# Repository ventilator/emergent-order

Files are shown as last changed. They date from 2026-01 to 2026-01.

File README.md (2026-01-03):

# /dev/emergent_order

An experiment in chaos and structure, presented at 39c3 (39th Chaos Communication Congress).

A 1×1×1m LED cube art installation filled with 1200 individually addressable WS2812B LEDs, creating a volumetric 3D display.

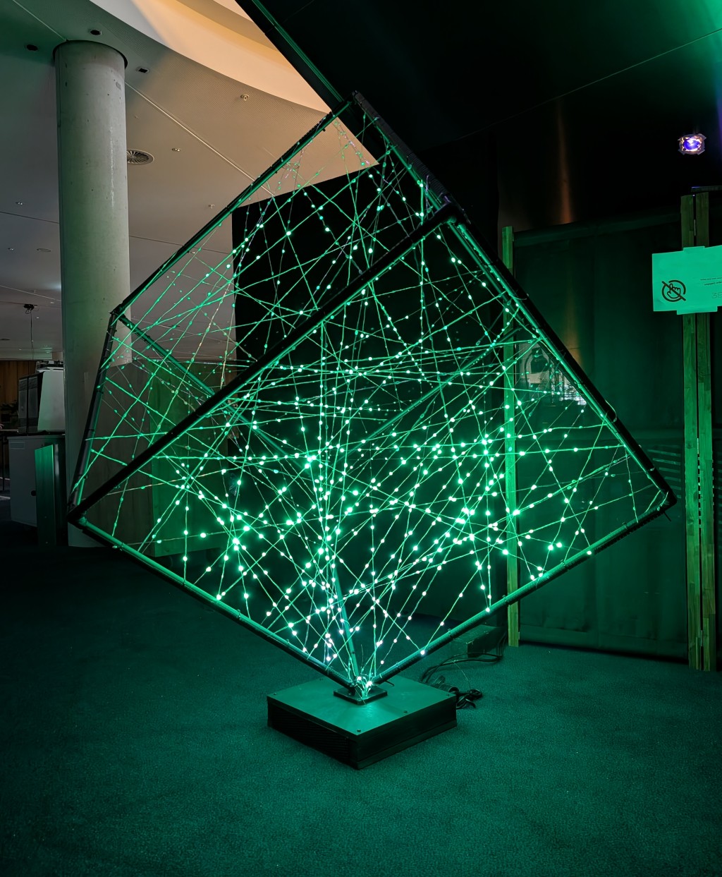
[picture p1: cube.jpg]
Assembled LED cube


## Overview

This repository contains most materials involved in creating the LED cube installation: software, firmware, animations, 3D mechanical parts, PCB designs, calibration tools, and documentation. The aim is to document the complete structure of the cube and make relevant tools and designs available to others who want to build their own version, learn from the project, create derivative works, or apply these concepts in entirely new ways.

## Project Structure

This repository contains the following subdirectories:

**Note:** Some directories mentioned below may not yet be available in the repository. We are actively uploading the remaining materials and expect to have everything published within the next few days.

### Hardware & Electronics

- **`controller_pcb/`** - KiCad project for a high-performance 8-channel WS2812 controller based on the Raspberry Pi Pico. Features include USB streaming mode, standalone operation with built-in test patterns, SD card playback, comprehensive monitoring (voltage, current, temperature), and per-channel smart fuse protection (3.7A). Supports up to 200 LEDs per channel at 60Hz. See [controller_pcb/README.md](controller_pcb/README.md) for complete specifications.

- **`pico_firmware/`** - C firmware for the Raspberry Pi Pico that drives 8 independent WS2812B channels via PIO hardware. Features gamma correction, automatic current limiting, hardware monitoring (temperature, current, voltage), channel fault detection, and built-in test patterns including a ternary-encoded calibration pattern for camera-based position recovery. See [pico_firmware/README.md](pico_firmware/README.md) for protocol specification and development setup.

- **`mechanical/`** - 3D printable parts (base, corners, combs, controller mounts) and carbon fiber tube specifications for building the physical cube structure. See [mechanical/README.md](mechanical/README.md) for details.

### Software & Control

- **`showrunner/`** - Node.js service that plays LED animations on the cube, streaming frames at 30-60 FPS over serial to the Pico firmware. Supports hot-swappable animations and WebSocket interface for live streaming. See [showrunner/README.md](showrunner/README.md) for details.

- **`animations/`** - JavaScript animation scripts that generate LED patterns using 3D math (SDF primitives, planes, spheres, fire effects, etc.). See [animations/README.md](animations/README.md) for examples and animation format.

- **`animation_designer/`** - Web-based tool for designing and previewing animations before deploying them to the cube. See [animation_designer/README.md](animation_designer/README.md) for usage instructions.

### Calibration & Utilities

- **`calibration/`** - Tools for recovering 3D LED positions from video captures of the cube. Includes video frame extraction, LED detection with ternary color-coded identification, and multi-camera 3D triangulation with bundle adjustment. Features both Python CLI tools and a web-based detector with real-time visualization. See [calibration/README.md](calibration/README.md) for complete workflow and encoding scheme documentation.

- **`ws2serial/`** - Python utility for testing and interfacing with WS2812 LED strips over USB serial during development. Provides a WebSocket-to-serial adapter allowing the animation designer web tool to stream pixel data over the network to the Pico controller. See [ws2serial/README.md](ws2serial/README.md) for details.

- **`testdevice/`** - MicroPython code for ESP32-C3 to quickly test single LED strings during installation and teardown. See [testdevice/README.md](testdevice/README.md) for details.

### Prototypes

- **`minikube/`** - Smaller ~20×20×20cm prototype cube with MicroPython firmware and mechanical designs for ESP32-C3. See [minikube/README.md](minikube/README.md) for details.

## Technical Specifications

- **Physical size:** 1×1×1 meter cube
- **LEDs:** 1200 individually addressable WS2812B LEDs
- **Structure:** Carbon fiber tubes (20×18mm) with 3D printed corner connectors
- **Controller:** Raspberry Pi Pico-based 8-channel controller (can be driven by Raspberry Pi 3 or run standalone)
- **Power:** Custom 4-layer PCB with 8-channel power distribution, smart fuse protection (3.7A per channel), and comprehensive monitoring
- **Software:** Node.js showrunner + JavaScript animation framework (USB streaming), or standalone test patterns
- **Communication:** USB serial (Pi 3 → Pico), PIO-based WS2812B output, WebSocket interface for live animation streaming

## Development Approach

Most of the code in this project was synthesized ("vibe coded") using various Anthropic Claude models. The goal was to rapidly prototype and get something working, so the code may not be well understood in all places or may contain bugs. However, key decisions about architecture, algorithms and artistic content were provided by humans, just not manually implemented line-by-line.

## License

See the license files in individual directories or license text in source files.

In general:
- **Code/Software:** MIT License
- **3D Models:** CC-BY 4.0
- **PCB Designs:** CERN-OHL-W (CERN Open Hardware License - Weakly Reciprocal)

## Contributing

This project was created for 39c3. Feel free to fork, modify, and create your own versions. If you build something based on this work, we'd love to hear about it!

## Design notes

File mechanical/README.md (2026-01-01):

# Mechanical Parts for LED Cube

This directory contains all the 3D models and specifications for building the physical structure of the 1×1×1m LED cube.

## Overview

The cube structure consists of:
- **Carbon fiber tubes** forming the main frame (12 edges of the cube)
- **3D printed connectors** to join the tubes at corners and base
- **3D printed cable management** combs to route LED wires
- **MDF base** housing all electronics
- **Controller mounting hardware**

## Bill of Materials

### Structural Components

#### Carbon Fiber Tubes

Ordered from "CARBON TIME" store on AliExpress:
- **Store:** [CARBON TIME](https://de.aliexpress.com/store/911756291)
- **Product:** [20mm Carbon Fiber Tubes](https://de.aliexpress.com/item/1005002337416341.html)

**Quantities needed:**
- 9× tubes 20×18×1000mm (outer × inner × length)
- 3× tubes 20×16×1000mm (for bottom connections to base)
  - Note: 20×18mm can be used for everything if you prefer consistency

**Finish:** Twill matte

#### MDF Base

The base houses all electronics and provides structural support:

- **Construction:** Two pieces of 40×40cm MDF + battens screwed together
- **Finish:** Painted black
- **Features:**
  - Houses Raspberry Pi 4, controller PCB, power supply
  - Covered by PLA honeycomb grills for visual cover and ventilation
  - 2× Noctua 40×40mm fans in the back for airflow
  - Cable access holes

### 3D Printed Parts

All 3D model files (.3mf format) are included in this directory. CAD source files are available on Onshape (links below).

#### Base Corner Connector

**File:** `base.3mf`

**Onshape CAD:** [View on Onshape](https://cad.onshape.com/documents/e40c83297a2b759d68be7f6e/w/c118c41bf27f27ad78296554/e/638a71450e9c66e4a3123774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)

**Quantity:** 1

**Purpose:** Holds three carbon fiber pipes at the bottom of the cube and secures them to the MDF base plate.

**Features:**
- Secured to base with 4× M5 screws
- Cable routing hole for LED wires

**Print Settings:**
- Material: PETG (recommended for strength)
- Layer height: 0.2mm
- Perimeter walls: 4+ for strength

**Assembly Notes:**
- This is a high-stress part - the 1m CF tubes create significant leverage
- While PETG prints work, aluminum parts would be more durable for permanent installations
- Handle the cube carefully to avoid breaking this part
- Print spare/replacement parts

---

#### Corner Connector

**File:** `corner.3mf`

**Onshape CAD:** [View on Onshape](https://cad.onshape.com/documents/e40c83297a2b759d68be7f6e/w/c118c41bf27f27ad78296554/e/c4481eaa0fdde92928e6f618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)

**Quantity:** 7 (one for each corner of the cube, except base)

**Purpose:** Connects 3 carbon fiber pipes at 90° angles to form cube corners.

**Print Settings:**
- Material: PETG
- Layer height: 0.2mm
- Shells/perimeters: 4+
- Orientation: Place on corner point for symmetric print

**Assembly Notes:**
- Friction fit design: pipes press into the connector
- Tolerances may vary: be prepared to file, sand, or heat-form for proper fit
- If fit is too loose: wrap electrical tape around CF tube end before inserting
- For permanent installations: consider adding set screws to secure tubes
- Not verified for prolonged thermal cycling (sun, seasons, etc.)

---

#### Cable Management Comb

**File:** `comb.3mf`

**Onshape CAD:** [View on Onshape](https://cad.onshape.com/documents/e40c83297a2b759d68be7f6e/w/c118c41bf27f27ad78296554/e/f5acbb86f4773182431e6e56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)

**Quantity:** 60 total (5 per 1m CF pipe × 12 pipes)

**Purpose:** Guides and organizes LED string wires along the carbon fiber tubes.

**Attachment:** Zip ties

**Print Settings:**
- Material: PLA (no significant structural load)
- Layer height: 0.2mm

**Assembly Notes:**
- Attach with small zip ties to CF tubes
- Route LED wires through the comb teeth

---

#### Controller PCB Mount

**File:** `controller_mount.3mf` and `controller_clamp.3mf`

**Onshape CAD:** [View on Onshape](https://cad.onshape.com/documents/70f768b329ba066f39a94f12/w/328bc72038fa8f24f8fcde96/e/15a5e0a3f1c87c68c4469b0a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)

**Quantity:** 1

**Purpose:** Provides solid base for the controller PCB and strain relief for LED cables.

**Features:**
- Screw mounting points for PCB (M3 threaded inserts required)
- Cable clamps for LED string wire management

**Print Settings:**
- Material: PLA or PETG
- Draft settings acceptable (fast print)
- May not need top/bottom solid layers (just perimeters)

**Assembly Notes:**
- Install M3 threaded inserts (heat-set recommended)
- Secure PCB with M3 screws
- Route LED cables through clamps before connecting to PCB

## License

3D models are licensed under [CC-BY 4.0](https://creativecommons.org/licenses/by/4.0/)

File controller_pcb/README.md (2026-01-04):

# 8-Channel WS2812 Controller

High-performance WS2812 LED controller based on the Raspberry Pi Pico, designed for driving large LED installations with up to 8 independent channels.

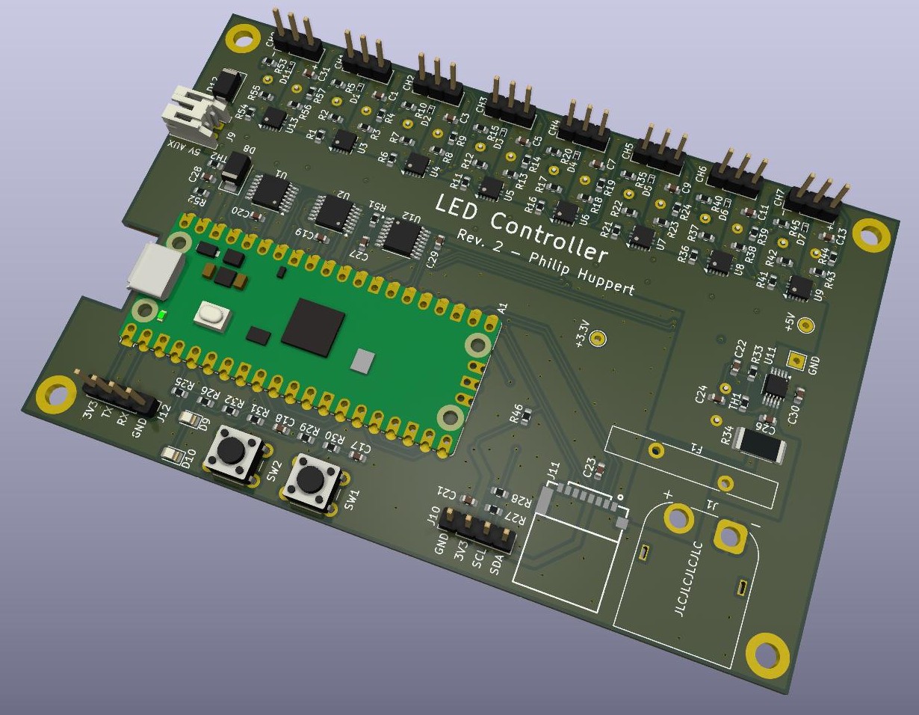
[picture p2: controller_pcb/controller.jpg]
Controller PCB


## Features

- **8 independent WS2812 channels** - Drive up to 200 LEDs per channel @ 60Hz
- **Multiple operation modes:**
  - USB streaming mode (real-time control from computer)
  - Standalone mode (run animations directly on Pico)
  - SD card playback mode (hardware ready, firmware not yet implemented)
- **Built-in test patterns** for calibration and diagnostics
- **Comprehensive monitoring** - voltage, current, and temperature sensing
- **Advanced protection** - smart fuses, PTC, and TVS diodes

## Hardware Specifications

### PCB Design
- **4-layer PCB**
- **Raspberry Pi Pico** microcontroller (direct solder or via header)
- Compact form factor

### LED Output Channels
- **8 independent channels** driven via PIO state machines
- **3.3V to 5V level shifters** for reliable WS2812 communication
- **Smart fuse protection** (TPS259251) set to 3.7A per channel
- **TVS diodes** on all data lines for protection

### Power System
- **5V input** via XT60 connector
- **Input PTC** for overcurrent protection
- **5V auxiliary output** for powering additional devices (fans, Raspberry Pi, etc.)
- **INA226 current/voltage monitor** for real-time power consumption tracking

### Sensing and Monitoring
- **Input power monitoring** via INA226 (voltage and current)
- **2× NTC temperature sensors** for thermal monitoring
- **Per-channel voltage sensing** via 8:1 analog multiplexer
- **Trip detection** - automatic fault detection when channels go offline

### User Interface
- **2 buttons** for pattern selection and reset
- **2 status LEDs** (activity and fault indicators)
- **I2C OLED display header** for local status display (optional)

### Storage
- **SD card slot** for storing animations and configuration files
- **Note:** SD card support is not currently implemented in the firmware, but it was verified that the slot is correctly wired and the Pico can access data on an SD card

## Implementation & Assembly Notes

### Capacitors
- The layout contains space for through-hole capacitors on the input rail and on each output rail
- These were not fitted on the controller that ran the installation and can be considered optional

### Channel Output Connectors
- The pin headers on the channel outputs do fit into JST-SM plugs commonly used with LED strings
- However, the spacing of the pin headers is too tight for two JST-SM plugs next to each other
- There is no mechanical interlocking, and if you pass any decent current (over 1A) these connections will get quite warm, especially if not well inserted
- **Recommendation:** For the controller used in the installation, we soldered pigtails with JST-SM sockets directly to the controller PCB for more reliable connections

### Pico Mounting
- The Pi Pico was mounted with a socket to allow easier exchange in case of failure
- This is recommended over direct soldering for serviceability

## Firmware

See `../pico_firmware/` for the Raspberry Pi Pico firmware source code.

## License

Hardware design licensed under **CERN-OHL-W** (CERN Open Hardware License - Weakly Reciprocal)

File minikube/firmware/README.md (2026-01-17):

# Minikube Firmware

MicroPython firmware to drive the LEDs of the minikube (single WS2812 string) with an ESP32-C3. Different ESP models or other microcontrollers may also work, provided they are capable of running MicroPython and driving a WS2812 string.

## Wiring Electronics

1. **Connect LED strip:**
   - Either solder strip directly to ESP32 pads, or use a connector
   - LED strip 5V to ESP32 VBUS
   - LED strip GND to ESP32 GND
   - LED data input to ESP32 pin 20 (configurable in `config.py`)

2. **Optional level shifter:**
   - Insert 3.3V to 5V level shifter between ESP32 and LED data line
   - A small PCB with 4× WS2812 LEDs works well for this purpose ([AliExpress link](https://de.aliexpress.com/item/1005010216258357.html))
   - Not strictly necessary but improves signal integrity

4. **Power the ESP32:**
   - Connect ESP32 via USB

   - Especially during development, while the ESP is connected to the USB port, it can happen that the PC does not deliver the required 500mA+ of power. On the console one can observe messages like "brown out detected, rebooting". If this is the case, consider powering the LED strip externally by connecting the 5V line of the LED strip to an external power supply. Do not forget to connect GND

## Installation Instructions

### 1. Flash MicroPython

Download MicroPython firmware for ESP32-C3 from [micropython.org](https://micropython.org/download/ESP32_GENERIC_C3/) and flash it using esptool.

### 2. Configure Settings

Edit `config.py` to configure:
- GPIO pin numbers
- Number of LEDs
- Other hardware-specific settings (see comments in file)

### 3. Upload Firmware

Upload all files from this directory to the ESP32 using [mpremote](https://docs.micropython.org/en/latest/reference/mpremote.html):

```bash
mpremote connect /dev/ttyACM0 cp -r * :
```

Windows (with com3 as the com port of your device):
```cmd
py -m mpremote connect com3 cp -r *
```

### 4. Verify Operation

Monitor serial output to ensure everything runs correctly:

```bash
mpremote connect /dev/ttyACM0
```

### 5. Calibrate LED Positions

For the animations to look correct, the exact 3D position of each LED must be known:

1. Press the boot button on the ESP32 to cycle to the **Calibration** animation
   - The calibration pattern displays a ternary-encoded LED ID sequence with magenta sync markers
   - Compatible with the camera-based calibration tools in `../../calibration/`
2. Capture calibration videos of the cube from multiple perspectives (6+ angles recommended)
   - Use fixed camera settings (exposure, white balance, focus)
   - Record the full calibration sequence from each angle
3. Process the videos and generate LED position data using the tools in `../../calibration/`
4. Upload the LED calibration results (positions) as `solution1.txt` to the ESP32:
   ```bash
   mpremote connect /dev/ttyACM0 cp solution1.txt :
   ```

After calibration, the volumetric animations will render correctly!

## Usage

- **Cycle animations:** Press the boot button of the ESP32
- **Modify animations:** Edit Python files in `animations/`
- **Create new animations:** Subclass `AnimationBase` and implement the `render()` method
- **Adjust speed/colors:** Modify parameters in the animation files

## Animation Framework

The firmware includes a simple animation framework:

- **`animation_base.py`** Base class for animations
- **`sdf_primitives.py`** Signed distance field primitives for 3D shapes
- **`math_utils.py`** Vector math, noise functions
- **`color_utils.py`** Color manipulation and conversion
- **`coordinate_loader.py`** Loads LED positions from calibration file

Example animations included:
- **`plane_animation.py`** Animated plane sweeping through the cube
- **`sphere_animation.py`** Pulsing sphere effect
- **`calibration.py`** Ternary-encoded calibration pattern for camera-based position recovery

## License

Firmware is licensed under MIT

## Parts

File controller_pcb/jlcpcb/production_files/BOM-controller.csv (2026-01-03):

Comment | Designator | Footprint | LCSC | Quantity
1000uF | C25 | C_Radial_D12.5mm_H20.0mm_P5.00mm | C88743 | 1
2.5m | R34 | R_2512_6332Metric | C7420002 | 1
470uF | C10,C12,C14,C2,C32,C4,C6,C8 | C_Radial_D10.0mm_H16.0mm_P5.00mm | C88732 | 8
74AHCT125 | U1,U2 | TSSOP-14_4.4x5mm_P0.65mm | C36365 | 2
74HC4051 | U12 | TSSOP-16_4.4x5mm_P0.65mm | C352826 | 1
Conn_01x02 | J1 | AMASS_XT60PW-M_1x02_P7.20mm_Horizontal | C98732 | 1
ESD9L5.0ST5G | D1,D11,D2,D3,D4,D5,D6,D7 | D_SOD-923 | C82326 | 8
INA226 | U11 | VSSOP-10_3x3mm_P0.5mm | C49851 | 1
Micro_SD_Card | J11 | TF-SMD_TF-021B-H265 | C498185 | 1
SS34 | D12,D8 | D_SMA | C8678 | 2
TPS259251 | U13,U3,U4,U5,U6,U7,U8,U9 | VSON-10-1EP_3x3mm_P0.5mm_EP1.65x2.4mm_ThermalVias | C527680 | 8
TRA1600 | F1 | Fuse_Bourns_MF-RHT1300 | C5678529 | 1
10K | R32 | R_0603_1608Metric |  | 1
10K | R29 | R_0603_1608Metric |  | 1
1K | R6 | R_0603_1608Metric |  | 1
47K | R44 | R_0603_1608Metric |  | 1
0.1uF | C19 | C_0603_1608Metric |  | 1
47K | R39 | R_0603_1608Metric |  | 1
0.1uF | C31 | C_0603_1608Metric |  | 1
47K | R19 | R_0603_1608Metric |  | 1
100K | R37 | R_0603_1608Metric |  | 1
0.1uF | C7 | C_0603_1608Metric |  | 1
330 | R10 | R_0603_1608Metric |  | 1
1K | R26 | R_0603_1608Metric |  | 1
33K | R3 | R_0603_1608Metric |  | 1
1K | R54 | R_0603_1608Metric |  | 1
1K | R11 | R_0603_1608Metric |  | 1
1K | R30 | R_0603_1608Metric |  | 1
0.1uF | C27 | C_0603_1608Metric |  | 1
0.1uF | C13 | C_0603_1608Metric |  | 1
330 | R35 | R_0603_1608Metric |  | 1
100K | R12 | R_0603_1608Metric |  | 1
33K | R38 | R_0603_1608Metric |  | 1
33K | R18 | R_0603_1608Metric |  | 1
0.1uF | C26 | C_0603_1608Metric |  | 1
10K | R28 | R_0603_1608Metric |  | 1
1K | R25 | R_0603_1608Metric |  | 1
0.1uF | C5 | C_0603_1608Metric |  | 1
1K | R41 | R_0603_1608Metric |  | 1
330 | R40 | R_0603_1608Metric |  | 1
100K | R42 | R_0603_1608Metric |  | 1
0.1uF | C9 | C_0603_1608Metric |  | 1
1K | R21 | R_0603_1608Metric |  | 1
33K | R43 | R_0603_1608Metric |  | 1
33K | R23 | R_0603_1608Metric |  | 1
330 | R53 | R_0603_1608Metric |  | 1
100K | R17 | R_0603_1608Metric |  | 1
0.1uF | C24 | C_0603_1608Metric |  | 1
10K | R52 | R_0603_1608Metric |  | 1
47K | R9 | R_0603_1608Metric |  | 1
0.1uF | C22 | C_0603_1608Metric |  | 1
0.1uF | C28 | C_0603_1608Metric |  | 1
1K | R16 | R_0603_1608Metric |  | 1
100K | R2 | R_0603_1608Metric |  | 1
TestPoint | TP1 | TestPoint_THTPad_2.0x2.0mm_Drill1.0mm |  | 1
TestPoint | TP3 | TestPoint_THTPad_D2.0mm_Drill1.0mm |  | 1
10K | TH1 | R_0603_1608Metric |  | 1
330 | R5 | R_0603_1608Metric |  | 1
100K | R7 | R_0603_1608Metric |  | 1
100K | R55 | R_0603_1608Metric |  | 1
10K | R51 | R_0603_1608Metric |  | 1
33K | R56 | R_0603_1608Metric |  | 1
330 | R45 | R_0603_1608Metric |  | 1
10K | R33 | R_0603_1608Metric |  | 1
47K | R24 | R_0603_1608Metric |  | 1
0.1uF | C29 | C_0603_1608Metric |  | 1
10K | R27 | R_0603_1608Metric |  | 1
10K | TH2 | R_0603_1608Metric |  | 1
1K | R36 | R_0603_1608Metric |  | 1
0.1uF | C21 | C_0603_1608Metric |  | 1
1K | R31 | R_0603_1608Metric |  | 1
0.1uF | C1 | C_0603_1608Metric |  | 1
1K | R1 | R_0603_1608Metric |  | 1
0.1uF | C3 | C_0603_1608Metric |  | 1
0.1uF | C30 | C_0603_1608Metric |  | 1
47K | R14 | R_0603_1608Metric |  | 1
0.1uF | C23 | C_0603_1608Metric |  | 1
0.1uF | C11 | C_0603_1608Metric |  | 1
0.1uF | C18 | C_0603_1608Metric |  | 1
330 | R20 | R_0603_1608Metric |  | 1
0.1uF | C17 | C_0603_1608Metric |  | 1
47K | R57 | R_0603_1608Metric |  | 1
TestPoint | TP2 | TestPoint_THTPad_D2.0mm_Drill1.0mm |  | 1
33K | R8 | R_0603_1608Metric |  | 1
33K | R13 | R_0603_1608Metric |  | 1
100K | R22 | R_0603_1608Metric |  | 1
0.1uF | C20 | C_0603_1608Metric |  | 1
330 | R15 | R_0603_1608Metric |  | 1
47K | R4 | R_0603_1608Metric |  | 1
Conn_01x02 | J9 | JST_PH_S2B-PH-K_1x02_P2.00mm_Horizontal |  | 1
10K | R46 | R_0603_1608Metric |  | 1

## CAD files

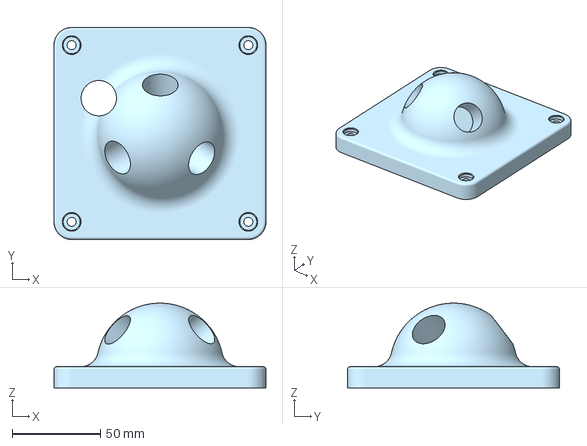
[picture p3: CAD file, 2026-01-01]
mechanical/base.3mf
120.0 x 120.0 x 48.0 mm

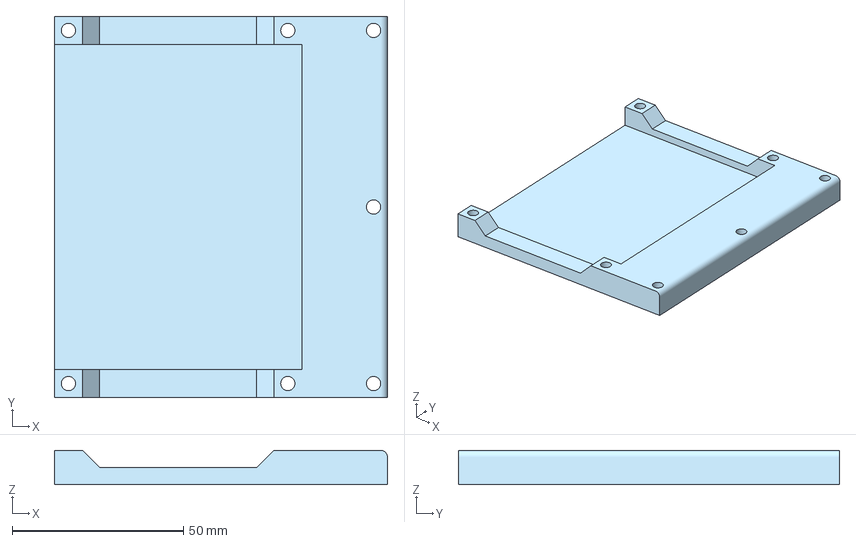
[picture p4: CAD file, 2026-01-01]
mechanical/controller_mount.3mf
97.2 x 111.2 x 10.0 mm

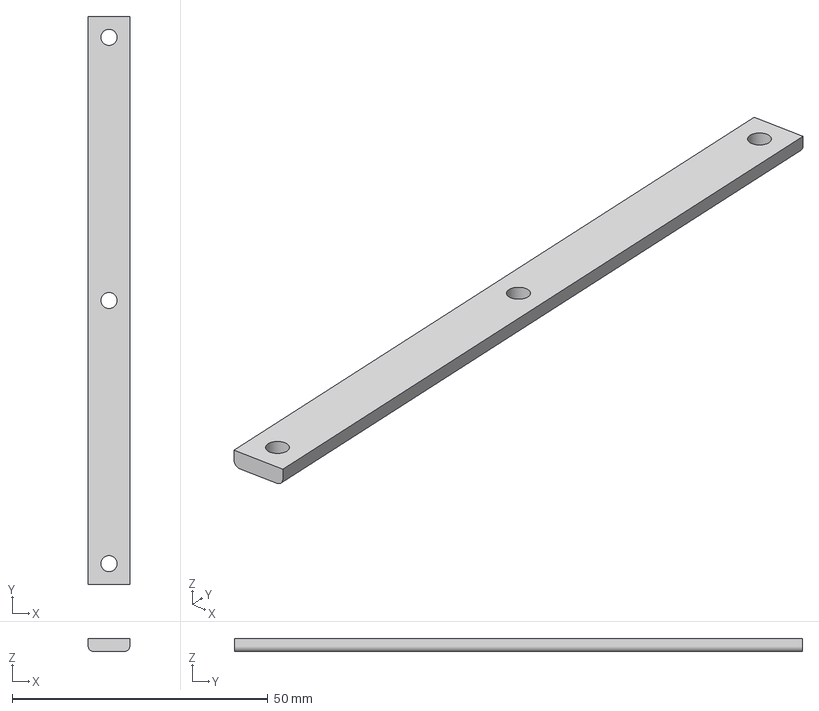
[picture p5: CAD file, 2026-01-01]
mechanical/controller_clamp.3mf
8.15 x 111.2 x 2.50 mm

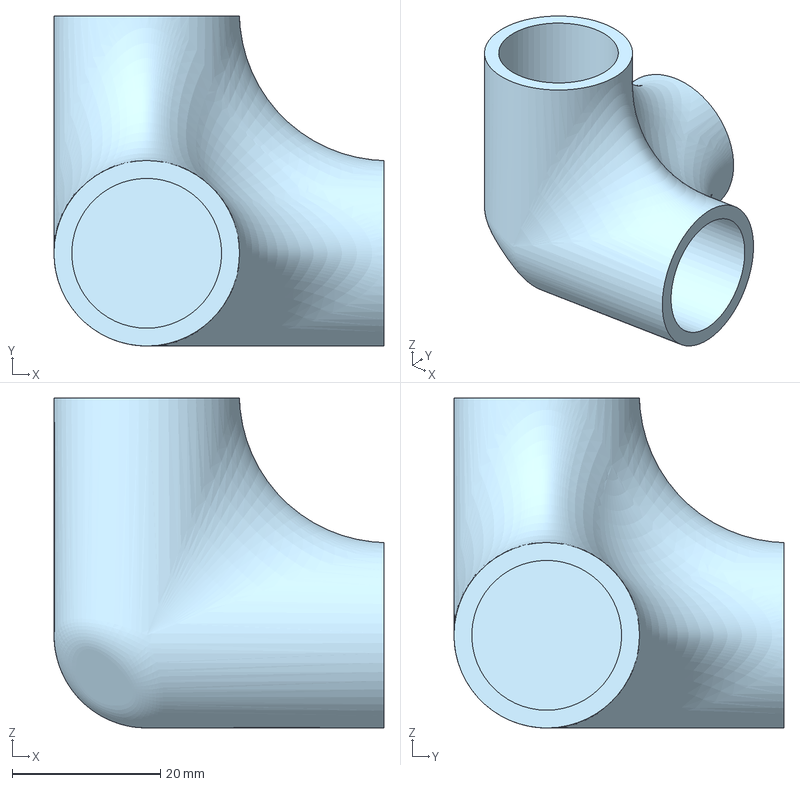
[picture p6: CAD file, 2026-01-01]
mechanical/corner.3mf
44.5 x 44.5 x 44.5 mm

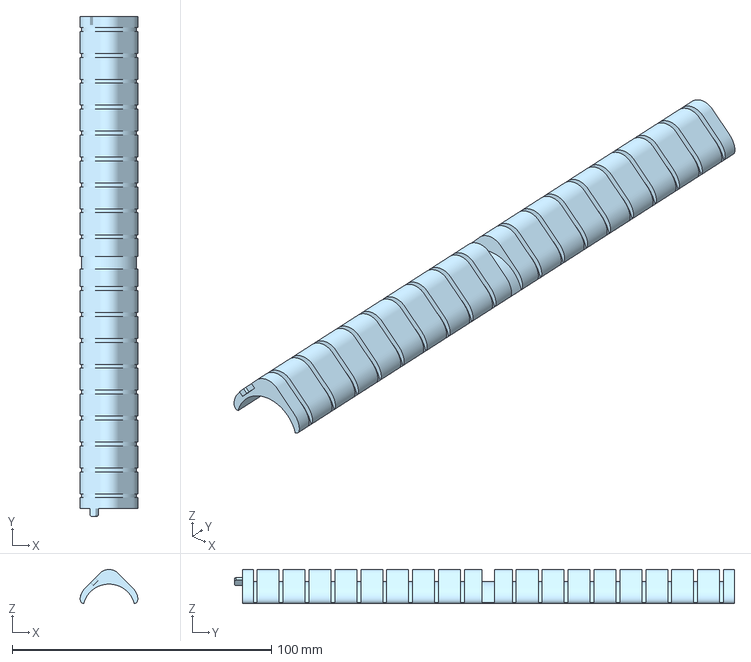
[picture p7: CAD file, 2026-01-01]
mechanical/comb.3mf
22.3 x 193.0 x 13.1 mm

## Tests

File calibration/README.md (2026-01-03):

# Cube Calibration Utils

Tools for recovering 3D LED positions from the chaotic LED cube installation.

## Overview

This calibration system uses a ternary color-coded identification scheme where LEDs flash specific color sequences that encode their unique IDs. Multiple camera perspectives capture these sequences, and the 2D detections are triangulated to recover 3D positions.

## Tools

### frame_extractor.py
Automated video processing tool that extracts calibration frames from video recordings.

**What it does:**
- Analyzes video frame-by-frame to detect brightness changes
- Identifies calibration sequences by detecting magenta color markers
- Extracts frames between magenta markers (configurable sequence length, default: 9 frames)
- Extracts corresponding dark frames for background subtraction
- Saves extracted frames as PNG files with structured naming

**Usage:**
```bash
uv run frame_extractor.py video.mp4
```

**Output:** PNG files named `{video_name}_subseq_{N}_{frame_number}.png` and `{video_name}_subseq_{N}_{frame_number}_dark.png`

### led_detector.html (+ .js + .css)
Modern web-based LED detector with real-time visual feedback.

**What it does:**
- Loads image sequences from a single camera perspective
- Performs background subtraction using dark frames
- Classifies pixel colors as Red, Green, Blue, or White
- Decodes ternary LED IDs from color sequences
- Validates LED IDs using checksum
- Computes LED centroid positions
- Exports results as text files

**Usage:**
Open `led_detector.html` in a web browser, drag and drop images (including dark frame and optional mask frame).

**Output format:**
```
FRAME_SIZE width height
LED_subseq_id x y
LED_subseq_id x y
...
```

### led_detector_sequenced.py
Command-line Python LED detector (legacy, less convenient than HTML version).

**What it does:**
Same functionality as HTML version but controlled via command-line arguments and environment variables.

**Usage:**
```bash
LOG_LEVEL=INFO DEBUG_OUTPUT=1 uv run led_detector_sequenced.py images/*.png
```

**Environment variables:**
- `LOG_LEVEL`: Logging verbosity (DEBUG, INFO, WARNING, ERROR)
- `DEBUG_OUTPUT`: Set to "1" to generate debug images

**Output:** Writes results to stdout, debug images if enabled

### rename_video.py
Simple utility for batch renaming video files (no external dependencies).

**What it does:**
Renames Google Pixel video files (format: `PXL_*.mp4`) to simple sequential names (`a.mp4`, `b.mp4`, `c.mp4`, etc.).

**Usage:**
```bash
./rename_video.py [directory]
```

If no directory is specified, operates on current directory.

### led_solver.py
3D reconstruction tool that triangulates LED positions from multiple camera perspectives.

**What it does:**
- Loads 2D LED observations from multiple cameras
- Performs camera calibration (estimates camera poses)
- Triangulates 3D LED positions using multiple views
- Applies bundle adjustment optimization
- Implements robust outlier rejection:
  - Statistical outlier detection (MAD-based)
  - RANSAC for camera pose estimation
  - Reprojection error validation
  - Iterative refinement
- Generates 3D visualization

**Usage:**
```bash
uv run led_solver.py camera1.txt camera2.txt camera3.txt --output solution.txt --viz visualization.html
```

**Optional arguments:**
- `--output`, `-o`: Output file for 3D LED positions
- `--viz`, `-v`: Generate HTML visualization
- `--top`: Comma-separated LED IDs near top (for orientation)
- `--bottom`: LED IDs near bottom
- `--left`: LED IDs near left
- `--right`: LED IDs near right

**Output format:**
```
LED_0000 -0.032561 0.357653 -0.102755
LED_0001 0.123456 -0.234567 0.345678
LED_0002 0.987654 0.654321 -0.123456
...
```
The solver may also output additional metadata and statistics as comments (lines starting with `#`).

## Full Calibration Workflow

### 1. Display Calibration Pattern
Run the calibration pattern on your LED installation. The pattern should:
- Flash magenta at the start and end of each sequence to mark boundaries
- Display 9 color frames (Red/Green/Blue) encoding LED IDs in ternary (see "LED ID Encoding Scheme" section below)
- Include dark frames (all LEDs off) between lit frames for background subtraction
- Allow enough time between color transitions for camera exposure (aim for 3-5 lit frames per color state)

### 2. Capture Videos
Record videos from multiple angles with consistent settings.

**Tested Configuration:**
- **Camera**: Google Pixel 9 Pro
- **Resolution**: 4K 60fps
- **Zoom**: 1x (no zoom)

**Critical Camera Settings:**
- **Fixed exposure** (lowest setting) - prevents LED overexposure and maintains consistency
- **Fixed color temperature** - ensures consistent color interpretation across frames
- **Fixed focus** - re-establish for each camera position, but don't change during recording
- **Ambient light** - provides context for the scene (will be removed via dark frame subtraction)
  - If LEDs are the only light source, color decoding may be unreliable

**Capture Guidelines:**
- Use a tripod for stability
- Capture at least 6+ perspectives for best results
- Vary camera angles significantly between captures
- Vary camera height - don't stay at ground level
- Ensure each camera can see a large portion of the cube (though close-up shots that capture smaller sections are also acceptable and can improve local accuracy)
- Avoid reflections in the environment, or mask them in post-processing
- Record one complete calibration sequence per perspective
- Don't move the cube or LEDs between captures

### 3. Rename and Extract Frames
```bash
# Rename video files for convenience (no dependencies, can run directly)
./rename_video.py /path/to/videos/

# Extract frames from each video
uv run frame_extractor.py a.mp4
uv run frame_extractor.py b.mp4
uv run frame_extractor.py c.mp4
# ... etc for each video
```

This produces frame files like:
```
a_subseq_01_0167_dark.png    (dark/background frame)
a_subseq_01_0179.png         (ternary digit 0)
a_subseq_01_0203.png         (ternary digit 1)
...
a_subseq_01_0324.png         (ternary digit 8)
```

### 4. Detect LED Positions
For each set of extracted frames:

1. Open `led_detector.html` in a web browser
2. Drag and drop all frames from one camera perspective (including dark frame)
3. Adjust parameters if needed:
   - **Brightness threshold**: Increase if too many false detections, decrease if missing LEDs
   - **Color purity**: Higher values require purer colors (reduces crosstalk)
   - **Green correction**: Adjust if greens appear blue/cyan
   - **Min pixels per LED**: Filter out small noise artifacts
4. Use masks to exclude reflections or unwanted regions
5. Verify detection quality using visualization modes
6. Click download button to save results
7. Save with consistent naming (e.g., `perspective_0.txt`, `perspective_1.txt`, ...)
8. Repeat for each camera perspective

### 5. Triangulate 3D Positions
```bash
uv run led_solver.py perspective_0.txt perspective_1.txt perspective_2.txt perspective_3.txt perspective_4.txt perspective_5.txt \
    --output led_positions_3d.txt \
    --viz led_positions_3d.html \
    --top 42,17 \
    --bottom 8,99
```

**Tips:**
- Use 6+ perspectives for robust reconstruction
- Provide spatial hints (top/bottom/left/right) if you know some LED positions - helps with orientation
- Check the HTML visualization for obvious errors
- Review rejection statistics to identify problematic cameras or LEDs
- If results are poor, try `--conservative` mode or add more camera angles

### 6. Verify Results
- Open the generated HTML visualization in a browser
- Rotate and inspect the 3D point cloud
- Check that the shape matches your physical installation
- Verify that LED IDs are reasonable and sequential
- Check solver statistics for high rejection rates (may indicate camera or detection issues)

**Note:** You may not achieve 100% calibration of all LEDs. A few "dead pixels" (heavily occluded, hidden, or failed detections) are acceptable. Animation software will set missing LEDs to black.

## LED ID Encoding Scheme

### Ternary Encoding
LEDs identify themselves by flashing a sequence of colors that encode their ID in ternary (base-3):

- **Red** = 0
- **Green** = 1
- **Blue** = 2
- **Least significant digit first** (right-to-left in conventional notation)

### Checksum Validation
To detect transmission errors, LED IDs include a built-in checksum:

1. The raw decoded ternary value must be divisible by 7 (i.e., `value % 7 == 0`)
2. If validation passes, divide by 9 to get the true LED ID: `true_id = value // 9`

### Encoding Example (Python)
```python
def encode_led_id(led_id: int, num_digits: int = 9) -> str:
    """Encode LED ID into ternary color sequence with checksum"""
    # Add checksum: multiply by 9, then add offset to ensure divisible by 7
    n = led_id * 9
    n = n + (7 - (n % 7))

    # Convert to ternary (LSB first)
    colors = []
    for _ in range(num_digits):
        digit = n % 3
        n = n // 3
        colors.append('RGB'[digit])

    return ''.join(colors)

def decode_led_id(color_sequence: str) -> int:
    """Decode ternary color sequence to LED ID, returns -1 if invalid"""
    # Decode ternary (LSB first)
    value = 0
    for i, color in enumerate(color_sequence):
        try:
            digit = 'RGB'.index(color)
        except ValueError:
            return -1  # Invalid color
        value += digit * (3 ** i)

    # Validate checksum
    if value % 7 != 0:
        return -1

    # Extract true ID
    true_id = value // 9
    return true_id

def generate_calibration_pattern(led_id: int, num_digits: int = 9) -> str:
    """Generate looping calibration pattern: _M_C_C_..._C_ (M=magenta, _=dark, C=color)"""
    # Encode the LED ID to get color sequence
    color_sequence = encode_led_id(led_id, num_digits)

    # Build the pattern: start with dark frame, then magenta marker
    pattern = ['_', 'M', '_']

    # Add each color frame followed by a dark frame
    for color in color_sequence:
        pattern.append(color)
        pattern.append('_')

    # Pattern loops back to initial dark frame (no explicit end marker needed)
    return ''.join(pattern)
```

### Example
For LED ID `1` with 9 digits:
- Base value: `1 * 9 = 9`
- Checksum offset: `7 - (9 % 7) = 7 - 2 = 5`
- Final value: `9 + 5 = 14`
- Verify: `14 % 7 = 0` ✓ (valid checksum)
- Decode check: `14 // 9 = 1` ✓ (recovers original ID)
- Ternary representation: `14 = 112` in base 3 (LSB first: 2, 1, 1)
- Color sequence: `BGGRRRRRR` (padded to 9 digits, R=0, G=1, B=2)
- Full calibration pattern: `_M_B_G_G_R_R_R_R_R_R_` (21 frames, then loops)
  - Frame 0: Dark (initial black frame)
  - Frame 1: Magenta (sync marker)
  - Frame 2: Dark
  - Frame 3: Blue (digit 0 = 2)
  - Frame 4: Dark
  - Frame 5: Green (digit 1 = 1)
  - Frame 6: Dark
  - ... (continues for all 9 color frames with dark frames between)
  - Frame 19: Red (digit 8 = 0)
  - Frame 20: Dark
  - (Pattern loops back to frame 0)

## License

MIT License

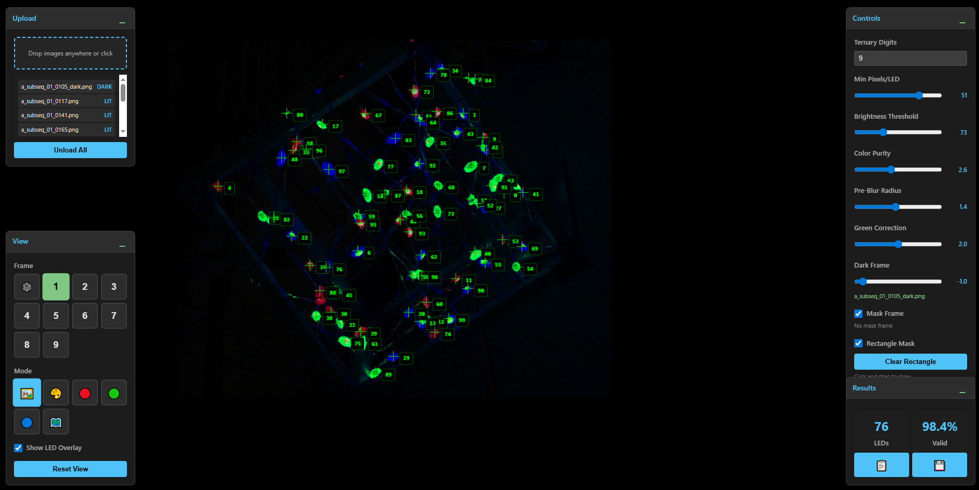
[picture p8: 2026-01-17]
calibration/examples/brightness_12.png

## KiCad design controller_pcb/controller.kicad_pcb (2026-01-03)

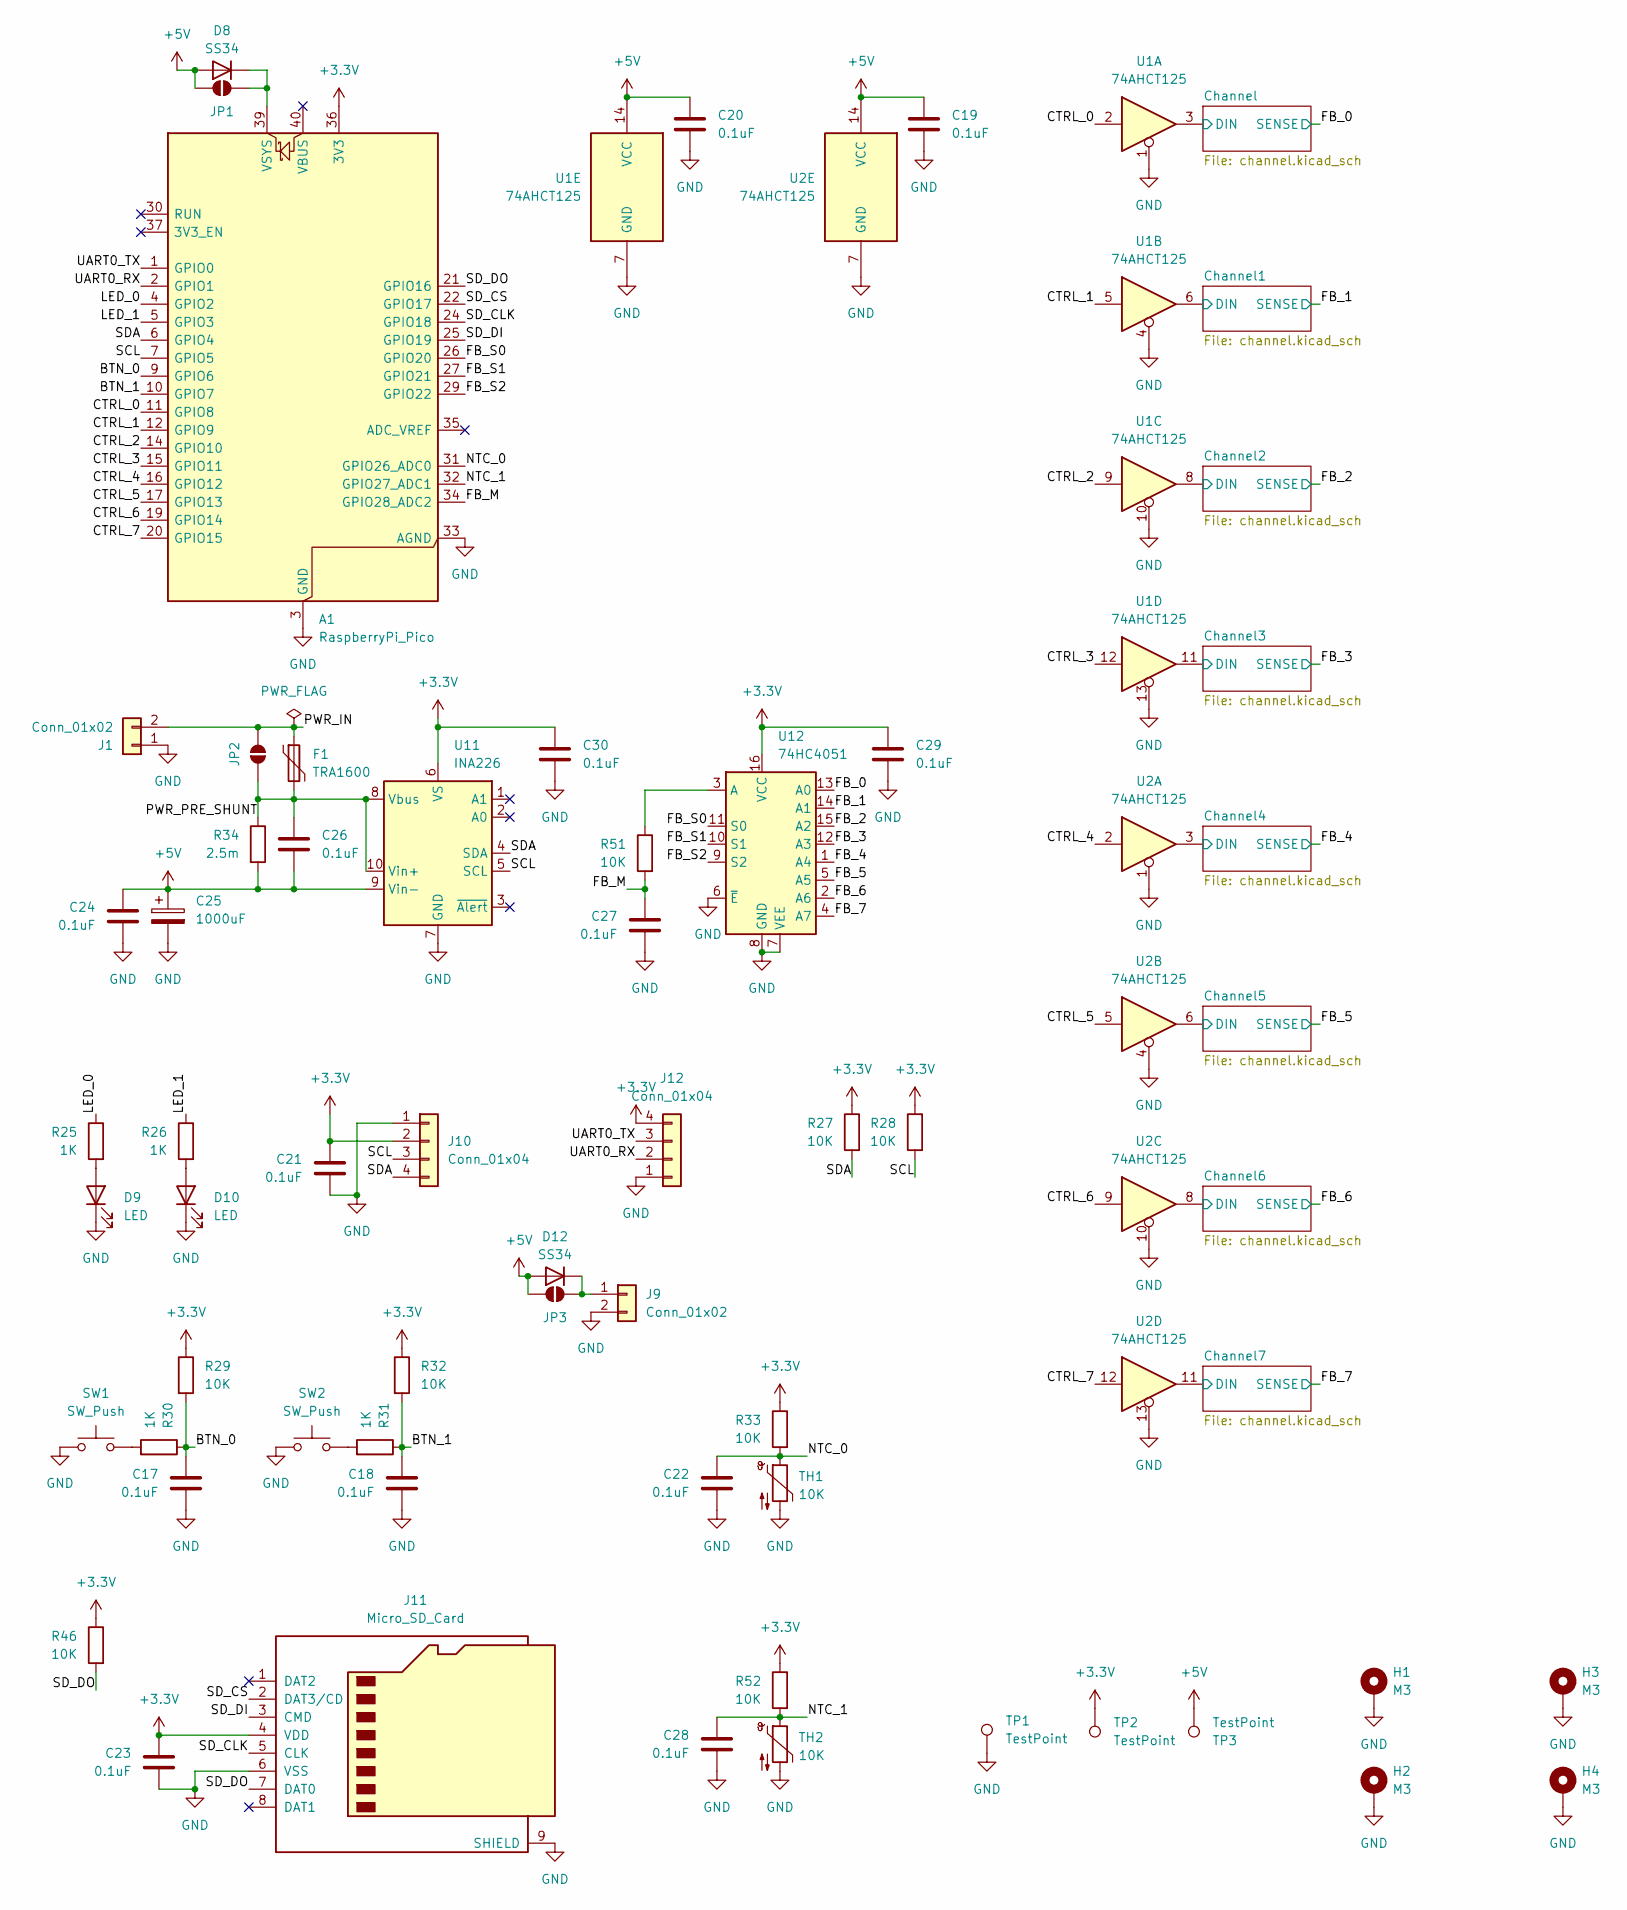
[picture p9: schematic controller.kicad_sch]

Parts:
A1: RaspberryPi_Pico; RaspberryPi_Pico_Common_Unspecified
C17, C18, C19, C20, C21, C22, C23, C24, C26, C27, C28, C29, C30: 0.1uF; C_0603_1608Metric
C25: 1000uF; C_Radial_D12.5mm_H20.0mm_P5.00mm; LCSC C88743
D8, D12: SS34; D_SMA; LCSC C8678
D9, D10: LED; LED_0805_2012Metric
F1: TRA1600; Fuse_Bourns_MF-RHT1300; LCSC C5678529
H1, H2, H3, H4: M3; MountingHole_3.2mm_M3_ISO7380_Pad_TopBottom
J1: Conn_01x02; AMASS_XT60PW-M_1x02_P7.20mm_Horizontal; LCSC C98732
J9: Conn_01x02; JST_PH_S2B-PH-K_1x02_P2.00mm_Horizontal
J10, J12: Conn_01x04; PinHeader_1x04_P2.54mm_Vertical
J11: Micro_SD_Card; TF-SMD_TF-021B-H265; LCSC C498185
JP1, JP2, JP3: SolderJumper_2_Open; SolderJumper-2_P1.3mm_Open_Pad1.0x1.5mm
R25, R26, R30, R31: 1K; R_0603_1608Metric
R27, R28, R29, R32, R33, R46, R51, R52: 10K; R_0603_1608Metric
R34: 2.5m; R_2512_6332Metric; LCSC C7420002
SW1, SW2: SW_Push; SW_PUSH_6mm_H5mm
TH1, TH2: 10K; R_0603_1608Metric
TP1: TestPoint; TestPoint_THTPad_2.0x2.0mm_Drill1.0mm
TP2, TP3: TestPoint; TestPoint_THTPad_D2.0mm_Drill1.0mm
U1, U2: 74AHCT125; TSSOP-14_4.4x5mm_P0.65mm; LCSC C36365
U11: INA226; VSSOP-10_3x3mm_P0.5mm; LCSC C49851
U12: 74HC4051; TSSOP-16_4.4x5mm_P0.65mm; LCSC C352826

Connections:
+3.3V: A1.36 (3V3), C21.1, C23.1, C29.1, C30.1, J10.2, J11.4 (VDD), J12.4, R27.1, R28.1, R29.1, R32.1, R33.1, R46.1, R52.1, TP2.1, U11.6 (VS), U12.16 (VCC)
+5V: C19.1, C20.1, C24.1, C25.1, C26.2, D8.2 (A), D12.2 (A), JP1.2 (B), JP3.2 (B), R34.2, TP3.1, U1.14 (VCC), U2.14 (VCC), U11.9 (Vin-); also elsewhere on the board
/BTN_0: A1.9 (GPIO6), C17.1, R29.2, R30.1
/BTN_1: A1.10 (GPIO7), C18.1, R31.1, R32.2
/CTRL_0: A1.11 (GPIO8), U1.2
/CTRL_1: A1.12 (GPIO9), U1.5
/CTRL_2: A1.14 (GPIO10), U1.9
/CTRL_3: A1.15 (GPIO11), U1.12
/CTRL_4: A1.16 (GPIO12), U2.2
/CTRL_5: A1.17 (GPIO13), U2.5
/CTRL_6: A1.19 (GPIO14), U2.9
/CTRL_7: A1.20 (GPIO15), U2.12
/Channel1/DIN: U1.6; also elsewhere on the board
/Channel2/DIN: U1.8; also elsewhere on the board
/Channel3/DIN: U1.11; also elsewhere on the board
/Channel4/DIN: U2.3; also elsewhere on the board
/Channel5/DIN: U2.6; also elsewhere on the board
/Channel6/DIN: U2.8; also elsewhere on the board
/Channel7/DIN: U2.11; also elsewhere on the board
/Channel/DIN: U1.3; also elsewhere on the board
/FB_0: U12.13 (A0); also elsewhere on the board
/FB_1: U12.14 (A1); also elsewhere on the board
/FB_2: U12.15 (A2); also elsewhere on the board
/FB_3: U12.12 (A3); also elsewhere on the board
/FB_4: U12.1 (A4); also elsewhere on the board
/FB_5: U12.5 (A5); also elsewhere on the board
/FB_6: U12.2 (A6); also elsewhere on the board
/FB_7: U12.4 (A7); also elsewhere on the board
/FB_M: A1.34 (GPIO28_ADC2), C27.1, R51.2
/FB_S0: A1.26 (GPIO20), U12.11 (S0)
/FB_S1: A1.27 (GPIO21), U12.10 (S1)
/FB_S2: A1.29 (GPIO22), U12.9 (S2)
/LED_0: A1.4 (GPIO2), R25.1
/LED_1: A1.5 (GPIO3), R26.1
/NTC_0: A1.31 (GPIO26_ADC0), C22.1, R33.2, TH1.1
/NTC_1: A1.32 (GPIO27_ADC1), C28.1, R52.2, TH2.1
/PWR_IN: F1.1, J1.2, JP2.2 (B)
/PWR_PRE_SHUNT: C26.1, F1.2, JP2.1 (A), R34.1, U11.8 (Vbus), U11.10 (Vin+)
/SCL: A1.7 (GPIO5), J10.3, R28.2, U11.5 (SCL)
/SDA: A1.6 (GPIO4), J10.4, R27.2, U11.4 (SDA)
/SD_CLK: A1.24 (GPIO18), J11.5 (CLK)
/SD_CS: A1.22 (GPIO17), J11.2 (DAT3/CD)
/SD_DI: A1.25 (GPIO19), J11.3 (CMD)
/SD_DO: A1.21 (GPIO16), J11.7 (DAT0), R46.2
/UART0_RX: A1.2 (GPIO1), J12.2
/UART0_TX: A1.1 (GPIO0), J12.3
GND: A1.3 (GND), A1.8 (GND), A1.13 (GND), A1.18 (GND), A1.23 (GND), A1.28 (GND), A1.33 (AGND), A1.38 (GND), C17.2, C18.2, C19.2, C20.2, C21.2, C22.2, C23.2, C24.2, C25.2, C27.2, C28.2, C29.2, C30.2, D9.1 (K), D10.1 (K), H1.1, H2.1, H3.1, H4.1, J1.1, J9.2, J10.1, J11.6 (VSS), J11.9 (SHIELD), J11.10 (SHIELD), J12.1, SW1.1, SW2.1, TH1.2, TH2.2, TP1.1, U1.1, U1.4, U1.7 (GND), U1.10, U1.13, U2.1, U2.4, U2.7 (GND), U2.10, U2.13, U11.7 (GND), U12.6 (~E), U12.7 (VEE), U12.8 (GND); also elsewhere on the board
unnamed: A1.39 (VSYS), D8.1 (K), JP1.1 (A)
unnamed: D9.2 (A), R25.2
unnamed: D10.2 (A), R26.2
unnamed: D12.1 (K), J9.1, JP3.1 (A)
unnamed: R30.2, SW1.2
unnamed: R31.2, SW2.2
unnamed: R51.1, U12.3 (A)

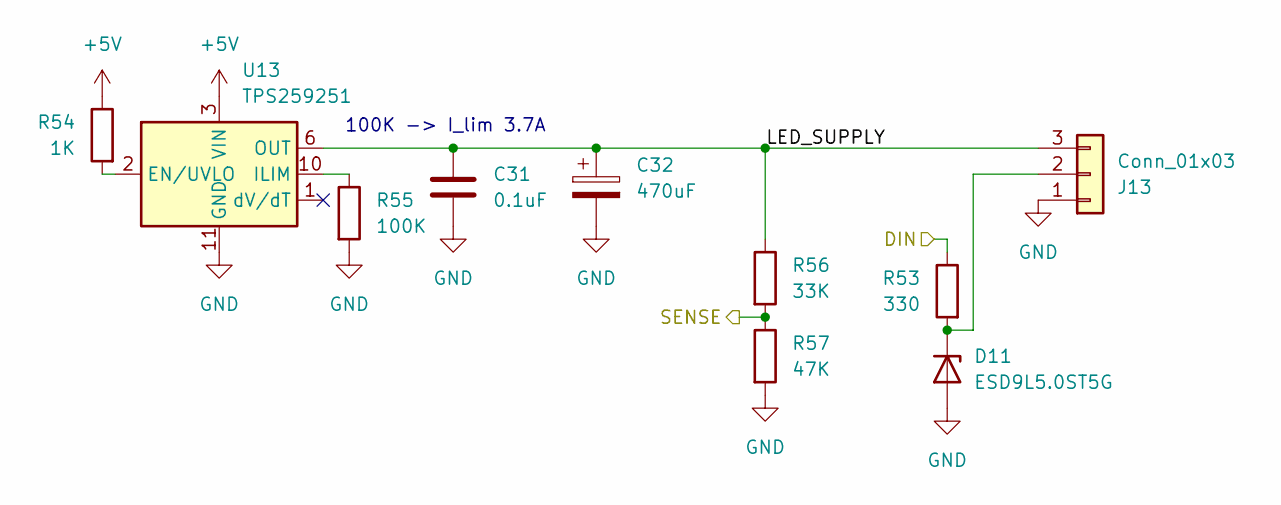
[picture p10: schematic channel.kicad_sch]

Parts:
C31: 0.1uF; C_0603_1608Metric
C32: 470uF; C_Radial_D10.0mm_H16.0mm_P5.00mm; LCSC C88732
D11: ESD9L5.0ST5G; D_SOD-923; LCSC C82326
J13: Conn_01x03; PinHeader_1x03_P2.54mm_Vertical
R53: 330; R_0603_1608Metric
R54: 1K; R_0603_1608Metric
R55: 100K; R_0603_1608Metric
R56: 33K; R_0603_1608Metric
R57: 47K; R_0603_1608Metric
U13: TPS259251; VSON-10-1EP_3x3mm_P0.5mm_EP1.65x2.4mm_ThermalVias; LCSC C527680

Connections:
+5V: R54.1, U13.3 (VIN), U13.4 (VIN), U13.5 (VIN); also elsewhere on the board
/Channel/DIN: R53.1; also elsewhere on the board
/Channel/LED_SUPPLY: C31.1, C32.1, J13.3, R56.1, U13.6 (OUT), U13.7 (OUT), U13.8 (OUT)
/FB_0: R56.2, R57.1; also elsewhere on the board
GND: C31.2, C32.2, D11.2 (A), J13.1, R55.2, R57.2, U13.11 (GND); also elsewhere on the board
unnamed: D11.1 (K), J13.2, R53.2
unnamed: R54.2, U13.2 (EN/UVLO)
unnamed: R55.1, U13.10 (ILIM)

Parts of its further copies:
C1, C3, C5, C7, C9, C11, C13: 0.1uF; C_0603_1608Metric
C2, C4, C6, C8, C10, C12, C14: 470uF; C_Radial_D10.0mm_H16.0mm_P5.00mm; LCSC C88732
D1, D2, D3, D4, D5, D6, D7: ESD9L5.0ST5G; D_SOD-923; LCSC C82326
J2, J3, J4, J5, J6, J7, J8: Conn_01x03; PinHeader_1x03_P2.54mm_Vertical
R1, R6, R11, R16, R21, R36, R41: 1K; R_0603_1608Metric
R2, R7, R12, R17, R22, R37, R42: 100K; R_0603_1608Metric
R3, R8, R13, R18, R23, R38, R43: 33K; R_0603_1608Metric
R4, R9, R14, R19, R24, R39, R44: 47K; R_0603_1608Metric
R5, R10, R15, R20, R35, R40, R45: 330; R_0603_1608Metric
U3, U4, U5, U6, U7, U8, U9: TPS259251; VSON-10-1EP_3x3mm_P0.5mm_EP1.65x2.4mm_ThermalVias; LCSC C527680

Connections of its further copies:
+5V: R1.1, R6.1, R11.1, R16.1, R21.1, R36.1, R41.1, U3.3 (VIN), U3.4 (VIN), U3.5 (VIN), U4.3 (VIN), U4.4 (VIN), U4.5 (VIN), U5.3 (VIN), U5.4 (VIN), U5.5 (VIN), U6.3 (VIN), U6.4 (VIN), U6.5 (VIN), U7.3 (VIN), U7.4 (VIN), U7.5 (VIN), U8.3 (VIN), U8.4 (VIN), U8.5 (VIN), U9.3 (VIN), U9.4 (VIN), U9.5 (VIN); also elsewhere on the board
/Channel1/DIN: R5.1; also elsewhere on the board
/Channel1/LED_SUPPLY: C1.1, C2.1, J2.3, R3.1, U3.6 (OUT), U3.7 (OUT), U3.8 (OUT)
/Channel2/DIN: R10.1; also elsewhere on the board
/Channel2/LED_SUPPLY: C3.1, C4.1, J3.3, R8.1, U4.6 (OUT), U4.7 (OUT), U4.8 (OUT)
/Channel3/DIN: R15.1; also elsewhere on the board
/Channel3/LED_SUPPLY: C5.1, C6.1, J4.3, R13.1, U5.6 (OUT), U5.7 (OUT), U5.8 (OUT)
/Channel4/DIN: R20.1; also elsewhere on the board
/Channel4/LED_SUPPLY: C7.1, C8.1, J5.3, R18.1, U6.6 (OUT), U6.7 (OUT), U6.8 (OUT)
/Channel5/DIN: R35.1; also elsewhere on the board
/Channel5/LED_SUPPLY: C9.1, C10.1, J6.3, R23.1, U7.6 (OUT), U7.7 (OUT), U7.8 (OUT)
/Channel6/DIN: R40.1; also elsewhere on the board
/Channel6/LED_SUPPLY: C11.1, C12.1, J7.3, R38.1, U8.6 (OUT), U8.7 (OUT), U8.8 (OUT)
/Channel7/DIN: R45.1; also elsewhere on the board
/Channel7/LED_SUPPLY: C13.1, C14.1, J8.3, R43.1, U9.6 (OUT), U9.7 (OUT), U9.8 (OUT)
/FB_1: R3.2, R4.1; also elsewhere on the board
/FB_2: R8.2, R9.1; also elsewhere on the board
/FB_3: R13.2, R14.1; also elsewhere on the board
/FB_4: R18.2, R19.1; also elsewhere on the board
/FB_5: R23.2, R24.1; also elsewhere on the board
/FB_6: R38.2, R39.1; also elsewhere on the board
/FB_7: R43.2, R44.1; also elsewhere on the board
GND: C1.2, C2.2, C3.2, C4.2, C5.2, C6.2, C7.2, C8.2, C9.2, C10.2, C11.2, C12.2, C13.2, C14.2, D1.2 (A), D2.2 (A), D3.2 (A), D4.2 (A), D5.2 (A), D6.2 (A), D7.2 (A), J2.1, J3.1, J4.1, J5.1, J6.1, J7.1, J8.1, R2.2, R4.2, R7.2, R9.2, R12.2, R14.2, R17.2, R19.2, R22.2, R24.2, R37.2, R39.2, R42.2, R44.2, U3.11 (GND), U4.11 (GND), U5.11 (GND), U6.11 (GND), U7.11 (GND), U8.11 (GND), U9.11 (GND); also elsewhere on the board
unnamed: D1.1 (K), J2.2, R5.2
unnamed: D2.1 (K), J3.2, R10.2
unnamed: D3.1 (K), J4.2, R15.2
unnamed: D4.1 (K), J5.2, R20.2
unnamed: D5.1 (K), J6.2, R35.2
unnamed: D6.1 (K), J7.2, R40.2
unnamed: D7.1 (K), J8.2, R45.2
unnamed: R1.2, U3.2 (EN/UVLO)
unnamed: R2.1, U3.10 (ILIM)
unnamed: R6.2, U4.2 (EN/UVLO)
unnamed: R7.1, U4.10 (ILIM)
unnamed: R11.2, U5.2 (EN/UVLO)
unnamed: R12.1, U5.10 (ILIM)
unnamed: R16.2, U6.2 (EN/UVLO)
unnamed: R17.1, U6.10 (ILIM)
unnamed: R21.2, U7.2 (EN/UVLO)
unnamed: R22.1, U7.10 (ILIM)
unnamed: R36.2, U8.2 (EN/UVLO)
unnamed: R37.1, U8.10 (ILIM)
unnamed: R41.2, U9.2 (EN/UVLO)
unnamed: R42.1, U9.10 (ILIM)

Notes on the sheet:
100K -> I_lim 3.7A

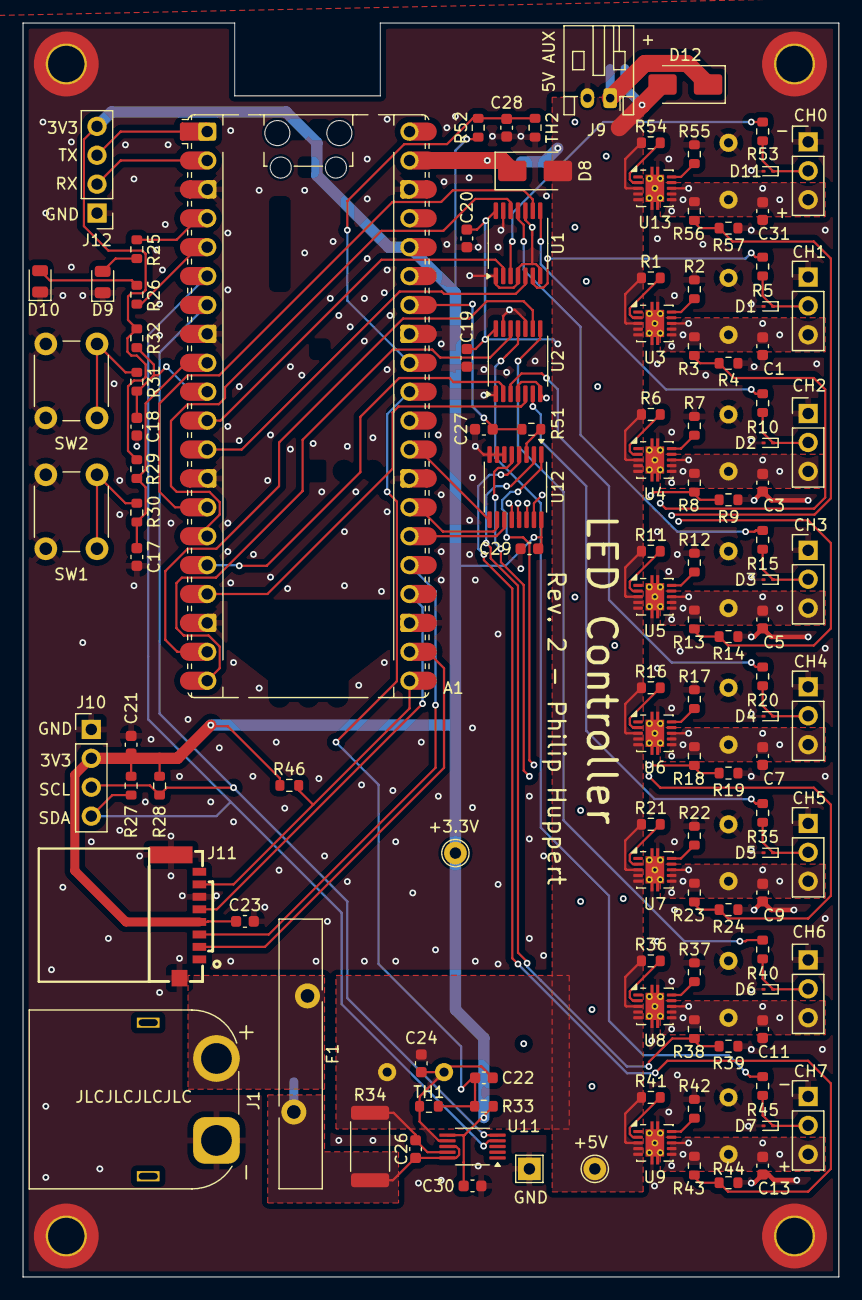
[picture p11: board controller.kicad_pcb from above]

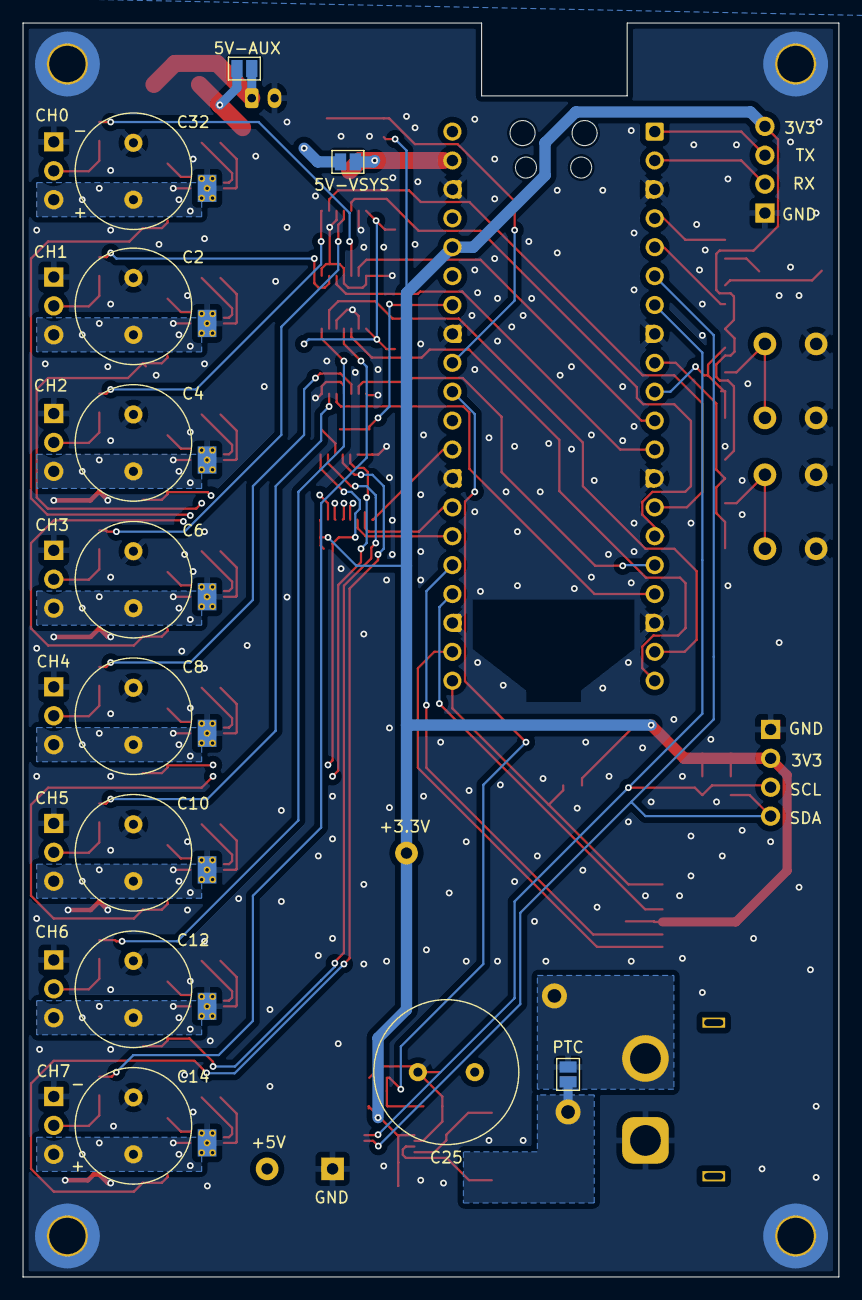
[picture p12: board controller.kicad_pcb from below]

Board: 4 copper layers, 71.7 x 110.2 mm, 136 parts (12 on the bottom side), 86 nets.

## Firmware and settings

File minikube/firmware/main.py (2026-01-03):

# LED Cube Animation System - Main Application
# MicroPython for ESP32-C3
# Based on testdevice.py architecture adapted for 3D coordinate-based animations

import machine
import neopixel
import time
import config
from coordinate_loader import load_coordinates
from animations.sphere_animation import SphereAnimation
from animations.plane_animation import PlaneAnimation
from animations.calibration import CalibrationAnimation


def clear_all(np):
    """Clear all LEDs to black"""
    for i in range(len(np)):
        np[i] = (0, 0, 0)
    np.write()


def main():
    """Main application loop"""
    print("\n" + "="*50)
    print("LED Cube Animation System")
    print("="*50)
    print(f"Hardware: ESP32-C3")
    print(f"Target FPS: {1000 // config.FRAME_TIME}")
    print(f"Brightness: {config.BRIGHTNESS}/255")
    print("="*50 + "\n")

    # Load and normalize LED coordinates
    print("Loading LED coordinates...")
    coords = load_coordinates('solution1.txt')
    print()

    # Calculate total LEDs needed (cube LEDs + built-in offset)
    num_leds = len(coords) + config.EXTERNAL_START
    print(f"Total LEDs in strip: {num_leds}")
    print(f"  Built-in LEDs: 0-{config.EXTERNAL_START - 1}")
    print(f"  Cube LEDs: {config.EXTERNAL_START}-{num_leds - 1}")
    print()

    # Initialize hardware
    print("Initializing hardware...")
    button = machine.Pin(config.BUTTON_PIN, machine.Pin.IN, machine.Pin.PULL_UP)
    np = neopixel.NeoPixel(machine.Pin(config.LED_PIN), num_leds)
    print(f"Button on GPIO {config.BUTTON_PIN}")
    print(f"LED strip on GPIO {config.LED_PIN}")
    print()

    # Define available animations
    animations = [
        ("Plane", PlaneAnimation),
        ("Sphere", SphereAnimation),
        ("Calibration", CalibrationAnimation),
    ]

    print("Available animations:")
    for i, (name, _) in enumerate(animations, 1):
        print(f"  {i}. {name}")
    print()

    # Initialize first animation
    animation_idx = 0
    animation_name, AnimationClass = animations[animation_idx]
    current_time = time.ticks_ms()
    current_animation = AnimationClass(coords, current_time)

    print(f"Starting animation: {animation_name}")
    print("Press button to switch animations")
    print("="*50 + "\n")

    # Clear LEDs
    clear_all(np)

    # Button state tracking
    last_button_state = 1
    button_press_time = 0

    # Status tracking
    last_status_time = time.ticks_ms()
    frame_count = 0
    total_frame_time = 0

    # Main loop
    try:
        while True:
            frame_start = time.ticks_ms()
            current_time = frame_start

            # Button handling with debouncing (same as testdevice.py)
            button_state = button.value()

            if button_state == 0 and last_button_state == 1:
                # Button just pressed
                button_press_time = current_time

            elif button_state == 0 and last_button_state == 0:
                # Button held down - check if debounce time passed
                if time.ticks_diff(current_time, button_press_time) >= config.BUTTON_DEBOUNCE:
                    # Wait for button release
                    while button.value() == 0:
                        time.sleep_ms(10)

                    # Switch to next animation
                    animation_idx = (animation_idx + 1) % len(animations)
                    animation_name, AnimationClass = animations[animation_idx]

                    print(f"Switching to animation: {animation_name}")

                    # Clear LEDs
                    clear_all(np)

                    # Create new animation instance
                    current_animation = AnimationClass(coords, time.ticks_ms())

                    # Reset button state
                    last_button_state = 1
                    continue

            last_button_state = button_state

            # Update animation
            current_animation.update(current_time, np)

            # Write to LEDs
            np.write()

            # Frame rate limiting
            elapsed = time.ticks_diff(time.ticks_ms(), frame_start)
            if elapsed < config.FRAME_TIME:
                time.sleep_ms(config.FRAME_TIME - elapsed)

            # Track frame statistics
            frame_count += 1
            total_frame_time += elapsed

            # Print status every second
            status_elapsed = time.ticks_diff(current_time, last_status_time)
            if status_elapsed >= 1000:
                avg_frame_time = total_frame_time / frame_count if frame_count > 0 else 0
                actual_fps = frame_count / (status_elapsed / 1000.0)
                print(f"[{animation_name}] FPS: {actual_fps:.1f} | Avg frame: {avg_frame_time:.1f}ms | Frames: {frame_count}")

                # Reset counters
                last_status_time = current_time
                frame_count = 0
                total_frame_time = 0

    except KeyboardInterrupt:
        print("\n" + "="*50)
        print("Shutting down...")
        clear_all(np)
        print("LEDs cleared. Goodbye!")
        print("="*50)


if __name__ == "__main__":
    main()

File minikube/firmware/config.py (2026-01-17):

# Hardware Configuration for LED Cube
# Based on testdevice.py configuration adapted for 74-LED cube

# GPIO Configuration
BUTTON_PIN = 0           # Boot button (active low with pull-up)
LED_PIN = 13             # WS2812 data line

# LED Strip Configuration
EXTERNAL_START = 0       # Offset for external cube LEDs in strip (skips built-in LEDs)

# Brightness Configuration
BRIGHTNESS = 30          # Power-saving brightness (0-255)
                        # Low brightness reduces USB power bank load

# Timing Configuration
FRAME_TIME = 33          # Target 30 FPS (33ms per frame)
BUTTON_DEBOUNCE = 50     # 50ms debounce window for button presses

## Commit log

2026-01-01 Add mechanical files and documentation
    [base.3mf, comb.3mf, controller_clamp.3mf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]
2026-01-01 Initial import of calibration utils
2026-01-03 Add calibration pattern to minikube firmware
2026-01-03 Import PCB design
    [BOM-controller.csv, channel.kicad_sch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]
2026-01-17 utf bugfix and custom calibration settings
    utf bugfix and custom calibration settings
    [config.py]
